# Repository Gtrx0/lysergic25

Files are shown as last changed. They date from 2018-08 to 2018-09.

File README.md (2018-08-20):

# Lysergic 25
5x5 Macropad PCB

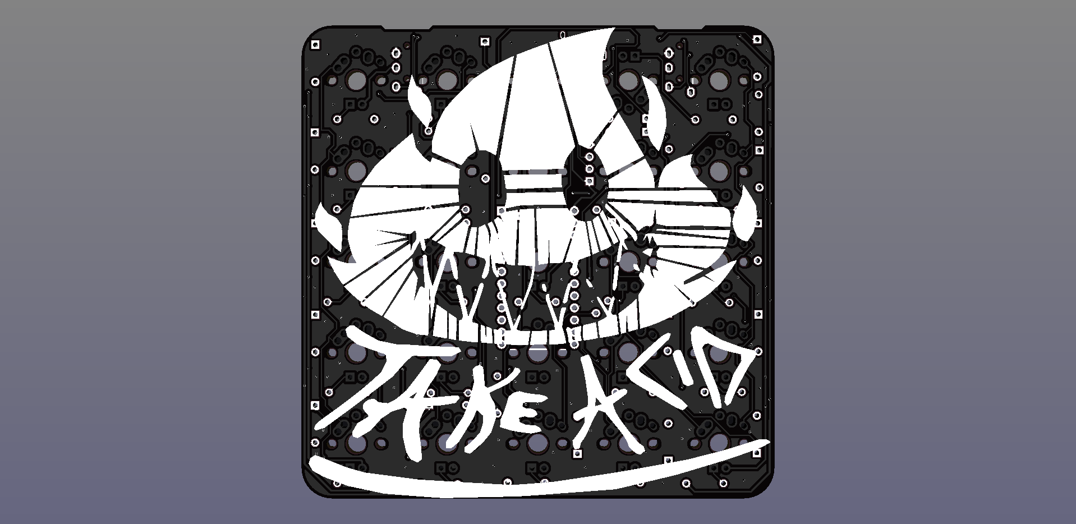
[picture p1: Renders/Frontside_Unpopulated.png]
Frontside Render

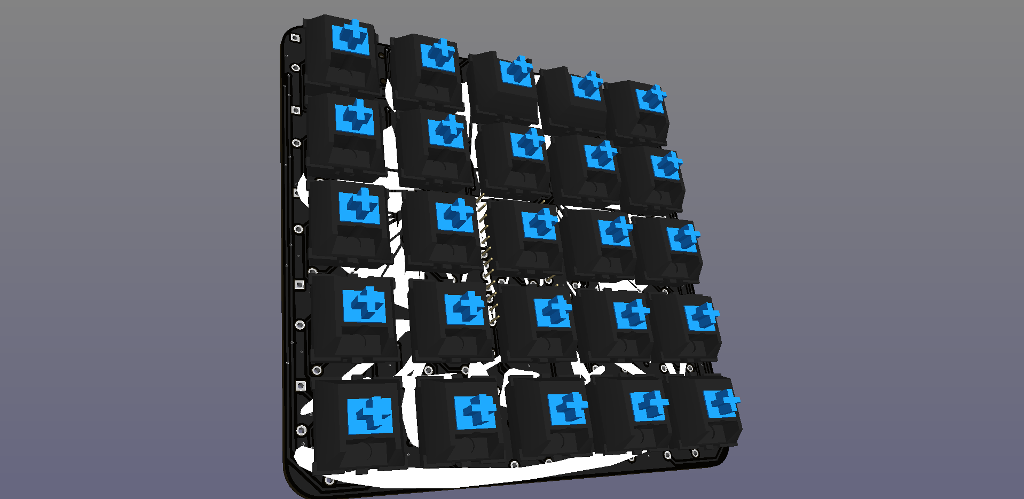
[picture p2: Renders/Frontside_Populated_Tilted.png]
Frontside Render

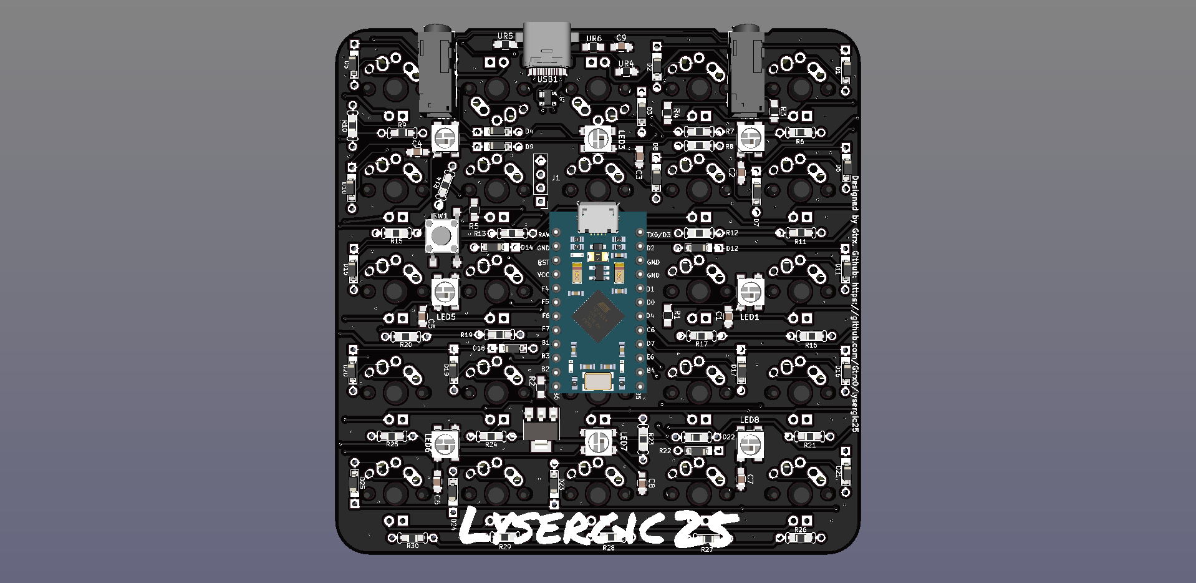
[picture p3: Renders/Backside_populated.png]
Backside Render

# [Layout](http://www.keyboard-layout-editor.com/#/gists/2997f919e892d07fd131f2b731a871e9)

## Features
* In-switch LED support.
* Individually addressible RGB underglow provided by 8 separate WS2812B LEDs.
* USB micro B to USB type-C converter which works like the one ergodox, so no more ripped off usb ports on your pro micro.
* Compatible with Cherry MX ALPS and Kailh CHOC switches. 
* Pro Micro microcontroller for easy diy assembly.
* USB ESD protection circuit.
* 0805 SMD and through hole Diode/resistor compatibility for ease of assembly.

## Warning
KiCad 5 or above is needed to open this project. KiCad 4 or below won't work.

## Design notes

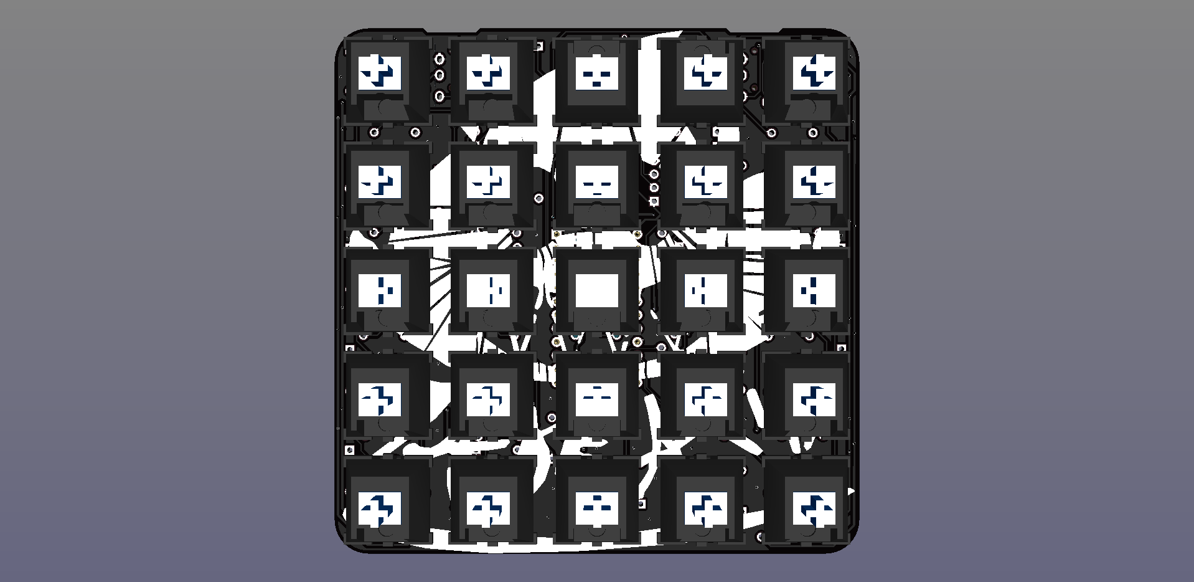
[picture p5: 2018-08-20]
Renders/Frontside_Populated.png

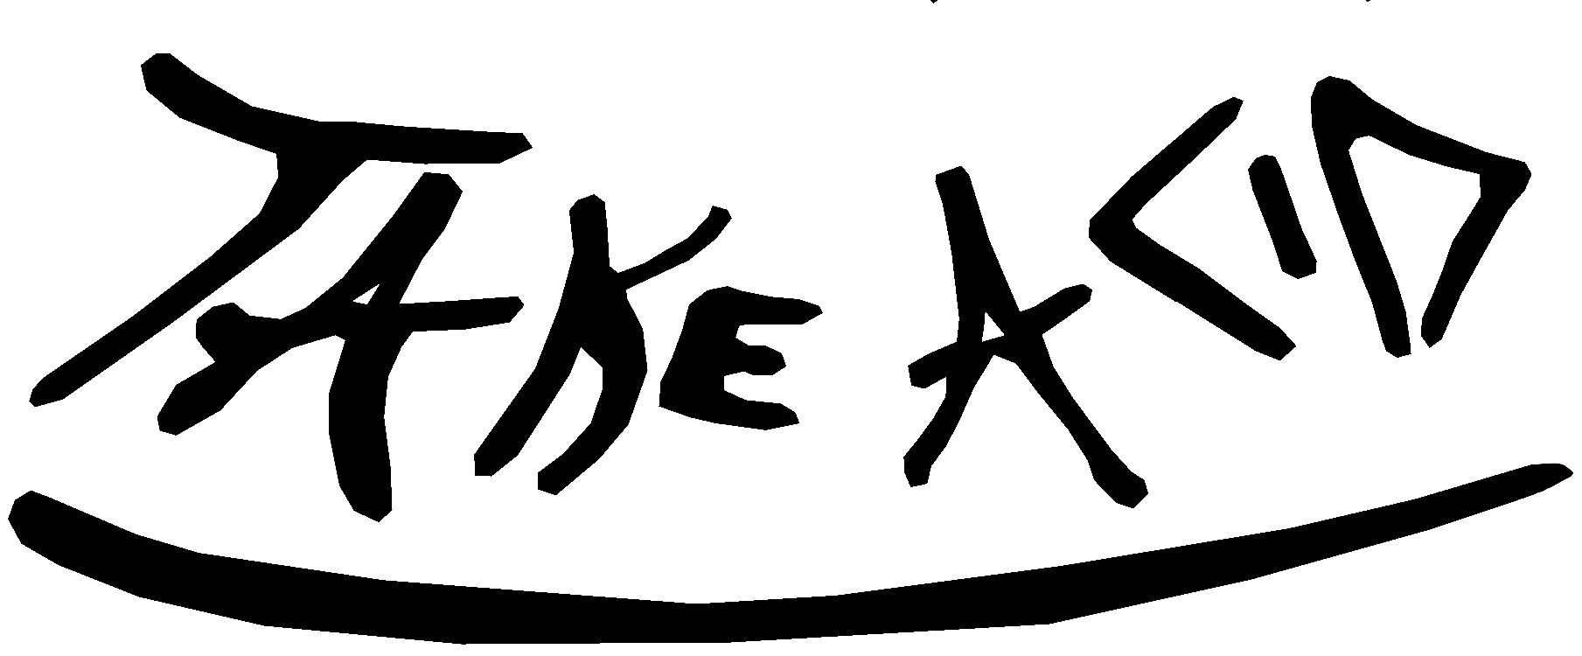
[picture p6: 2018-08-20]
Take_Acid/TAKEACID_text.bmp

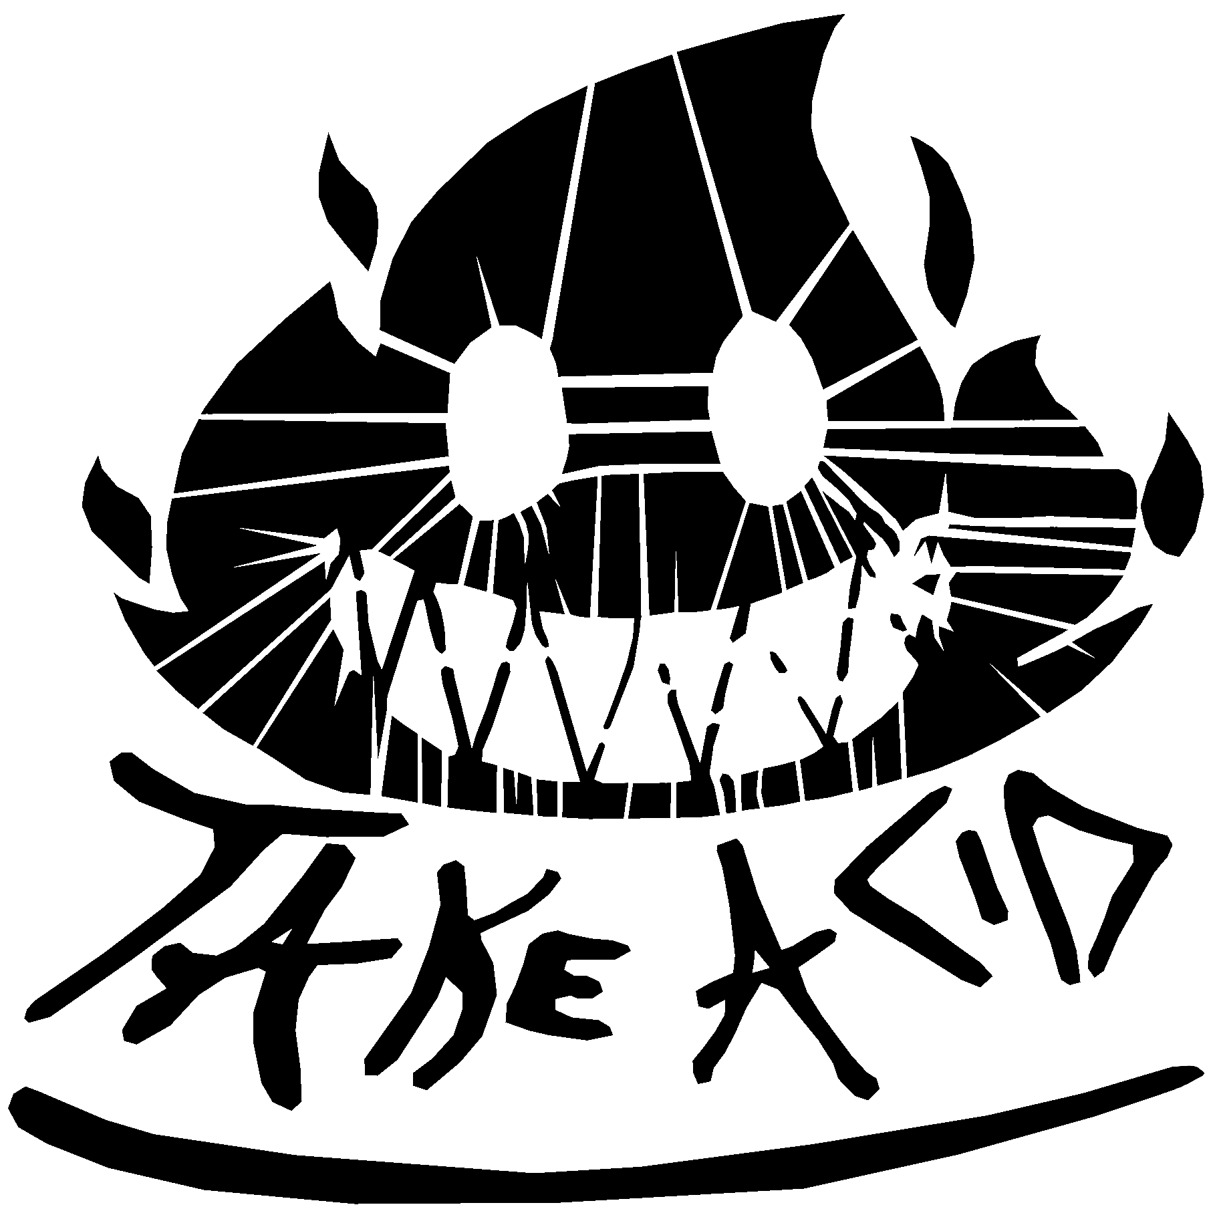
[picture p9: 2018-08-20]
Take_Acid/TAKEACID.bmp

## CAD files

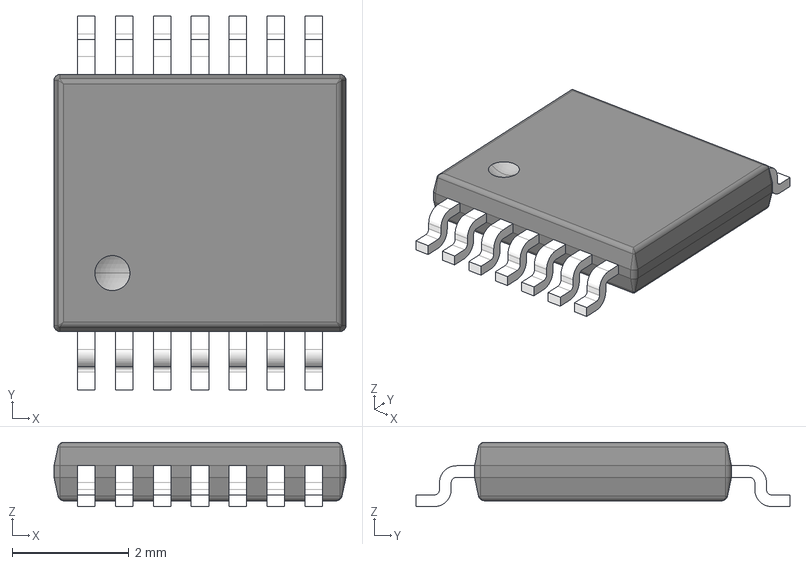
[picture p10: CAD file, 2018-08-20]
Nexperia/Nexperia/3D/SOT402 MO153 TSSOP14-1.step
5.00 x 6.40 x 1.10 mm

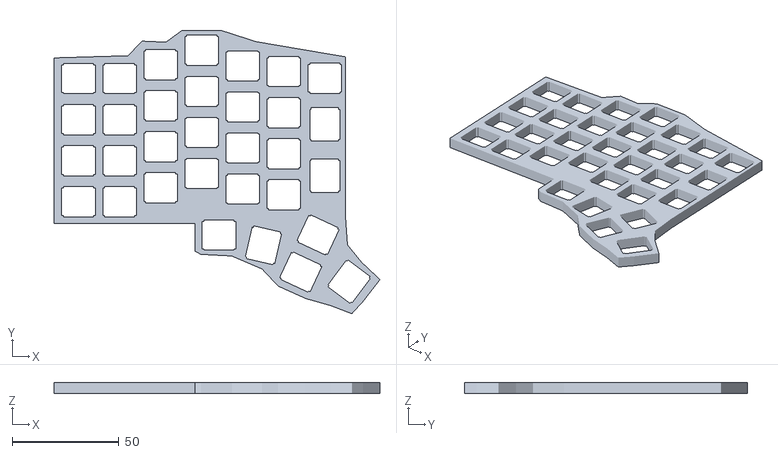
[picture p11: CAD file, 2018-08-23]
Plate/3d print PLATE and CASE (HIGHLY EXPERIMENTAL, 99% WONT WORK)/DNA 2 for thumbs.stl
152.6 x 132.7 x 5.36

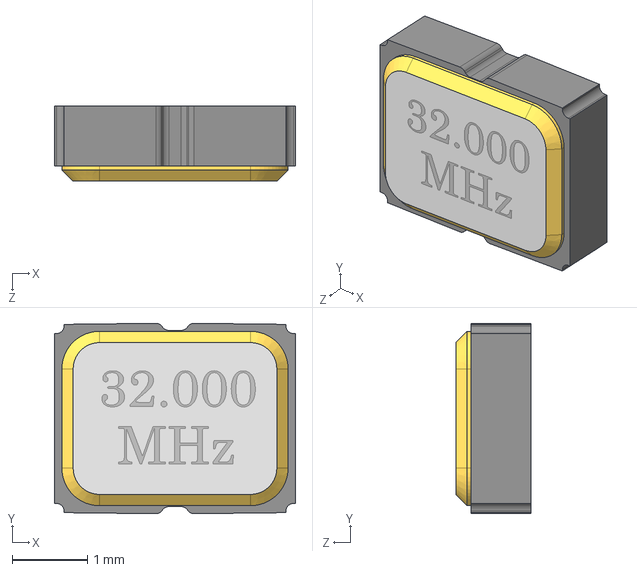
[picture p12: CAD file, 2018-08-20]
3D/OSC3225.STEP
3.20 x 2.53 x 1.00 mm

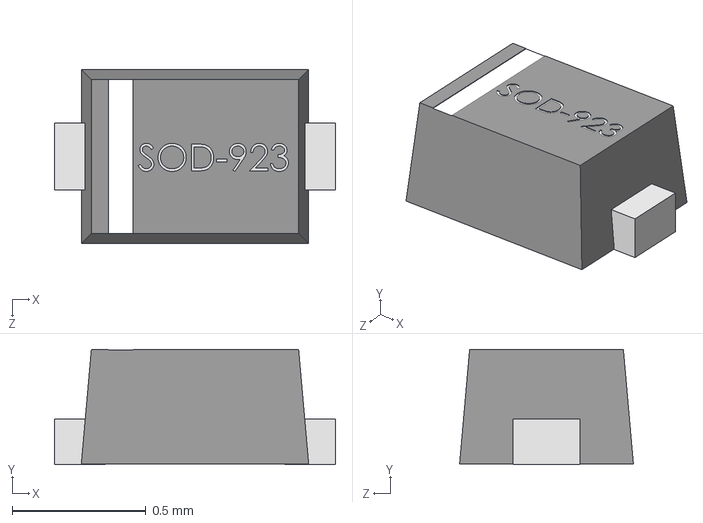
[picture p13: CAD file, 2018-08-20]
Nexperia/Nexperia/3D/SOD923.step
1.05 x 0.43 x 0.65 mm

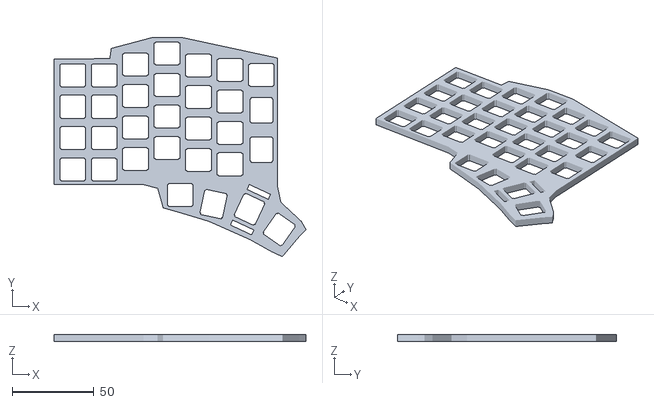
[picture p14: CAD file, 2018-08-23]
Plate/3d print PLATE and CASE (HIGHLY EXPERIMENTAL, 99% WONT WORK)/dna plate non weird.stl
153.9 x 133.9 x 4.29

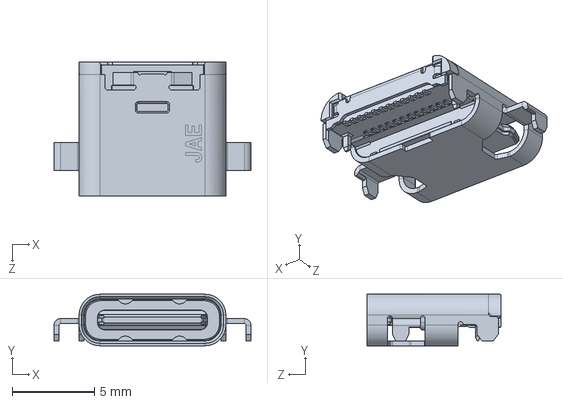
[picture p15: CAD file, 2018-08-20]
3D/K3D-DX07B024JJ1-V1_JAE_Proprietary.STEP
12.0 x 3.14 x 8.17 mm

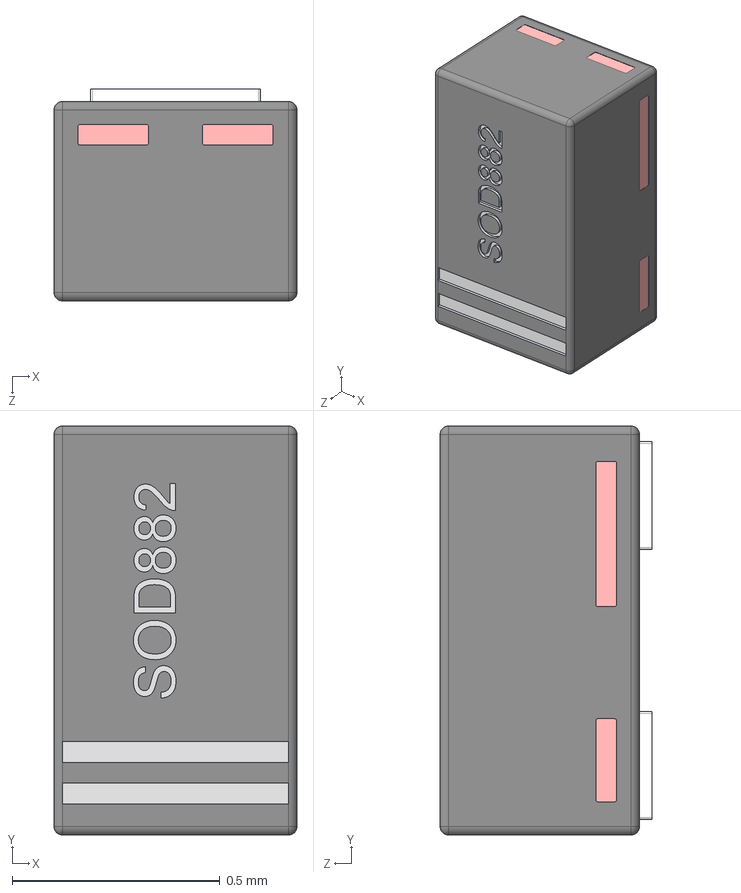
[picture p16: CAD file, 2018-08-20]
Nexperia/Nexperia/3D/SOD882-1.step
0.585 x 0.985 x 0.51 mm

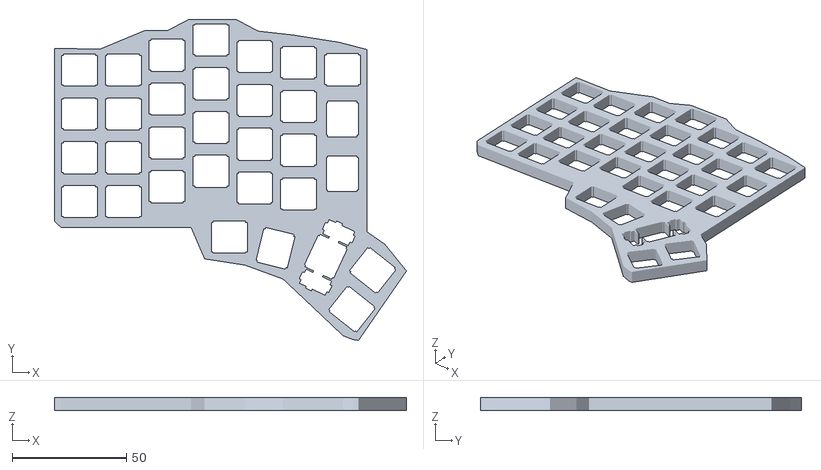
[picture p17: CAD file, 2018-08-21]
Plate/3d print PLATE and CASE (HIGHLY EXPERIMENTAL, 99% WONT WORK)/DNAPLATEREV2.stl
154.2 x 140.6 x 5.71

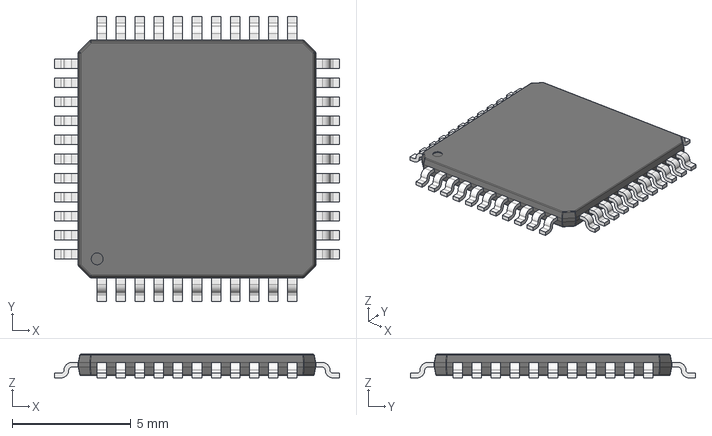
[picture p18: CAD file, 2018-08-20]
3D/qfp80p-10mmx10mm-44 v1.step
12.0 x 12.0 x 1.00 mm
icbody
pin0.25mm x 44

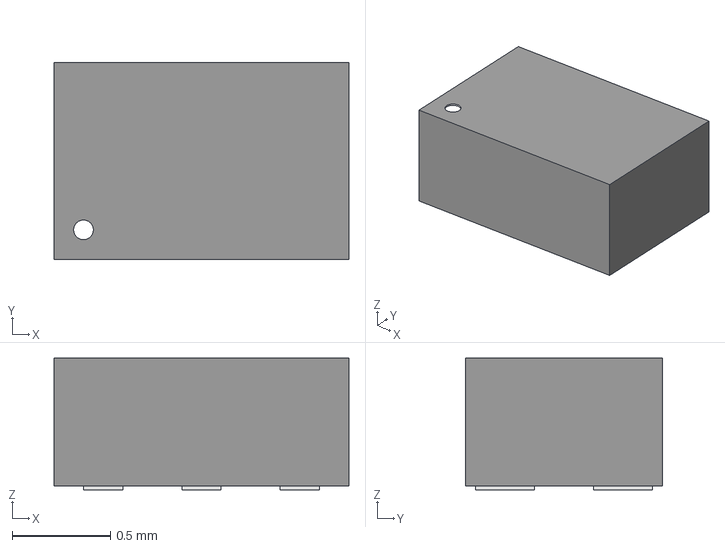
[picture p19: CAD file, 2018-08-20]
Nexperia/Nexperia/3D/MO-252D-UAAD.step
1.50 x 1.00 x 0.67 mm

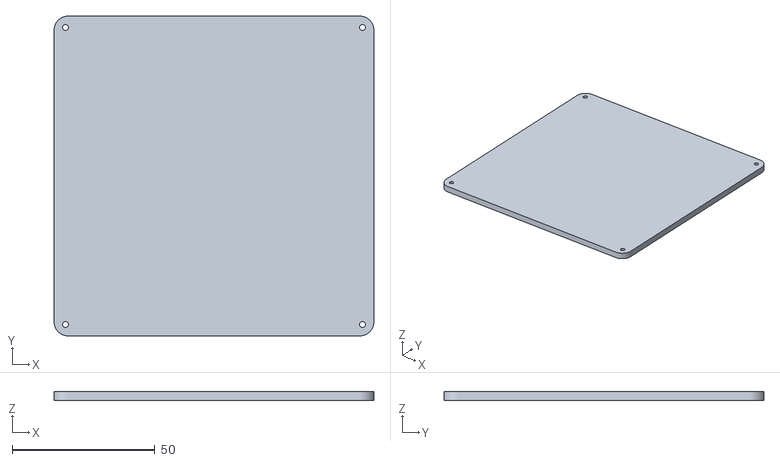
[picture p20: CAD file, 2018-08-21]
Plate/3d print PLATE and CASE (HIGHLY EXPERIMENTAL, 99% WONT WORK)/Lysergic_bottomPLATE.stl
112.1 x 112.1 x 3.01

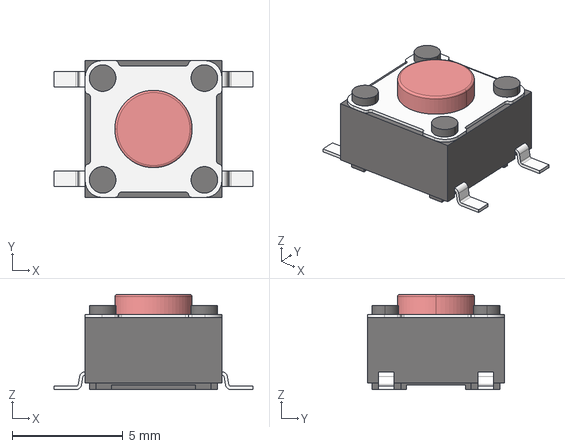
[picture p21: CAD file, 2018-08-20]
3D/Tact Switch SMD 6x6mm.stp
9.00 x 6.20 x 4.30 mm

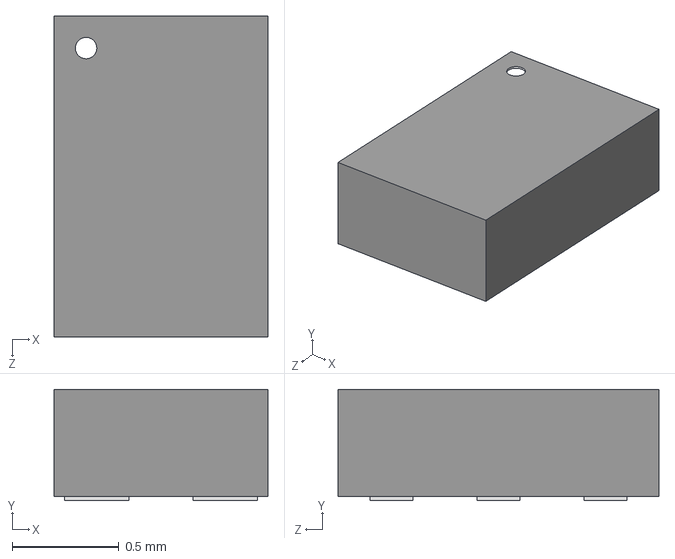
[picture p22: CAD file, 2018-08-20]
Nexperia/Nexperia/3D/MO-252DX1510D-6pin.STEP
1.00 x 0.52 x 1.50 mm

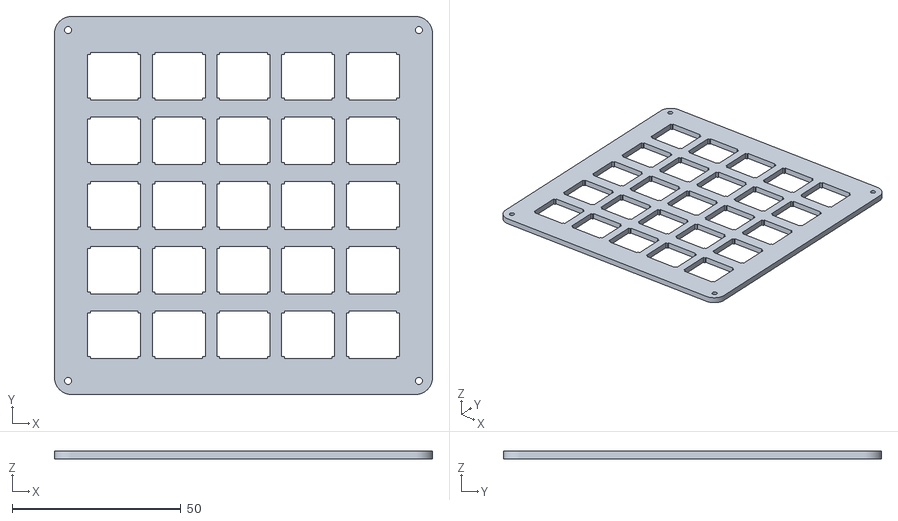
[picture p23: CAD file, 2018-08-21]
Plate/3d print PLATE and CASE (HIGHLY EXPERIMENTAL, 99% WONT WORK)/lysergicPLATE.stl
112.1 x 112.1 x 2.30

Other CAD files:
3D/WS2812_RGB_LED_updated.stp
Nexperia/Nexperia/3D/User Library-MO-252DU1510D (UAAD).STEP
3D/res1206r.STEP
Nexperia/Nexperia/3D/MO-252DU1510D (UAAD)-4pin.STEP
3D/FC68128.STEP
3D/TO-253AA.stp
Nexperia/Nexperia/3D/SC-70-6.stp
Nexperia/Nexperia/3D/SOT402 MO153 TSSOP14-1_orig.step

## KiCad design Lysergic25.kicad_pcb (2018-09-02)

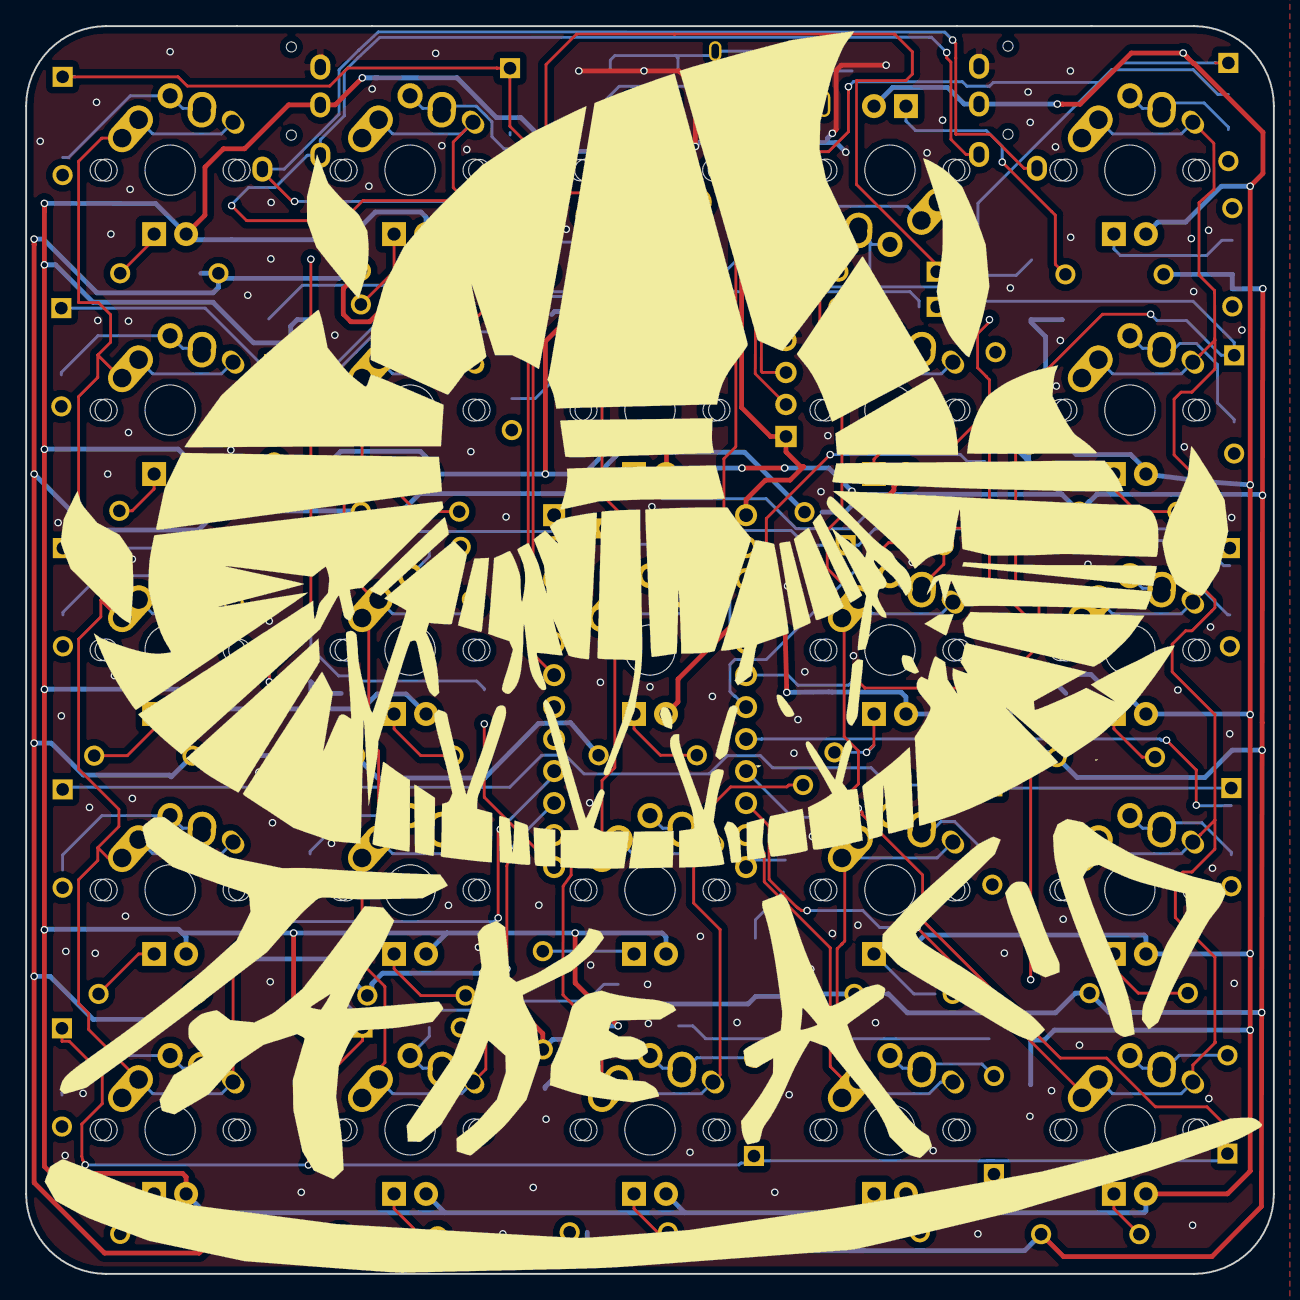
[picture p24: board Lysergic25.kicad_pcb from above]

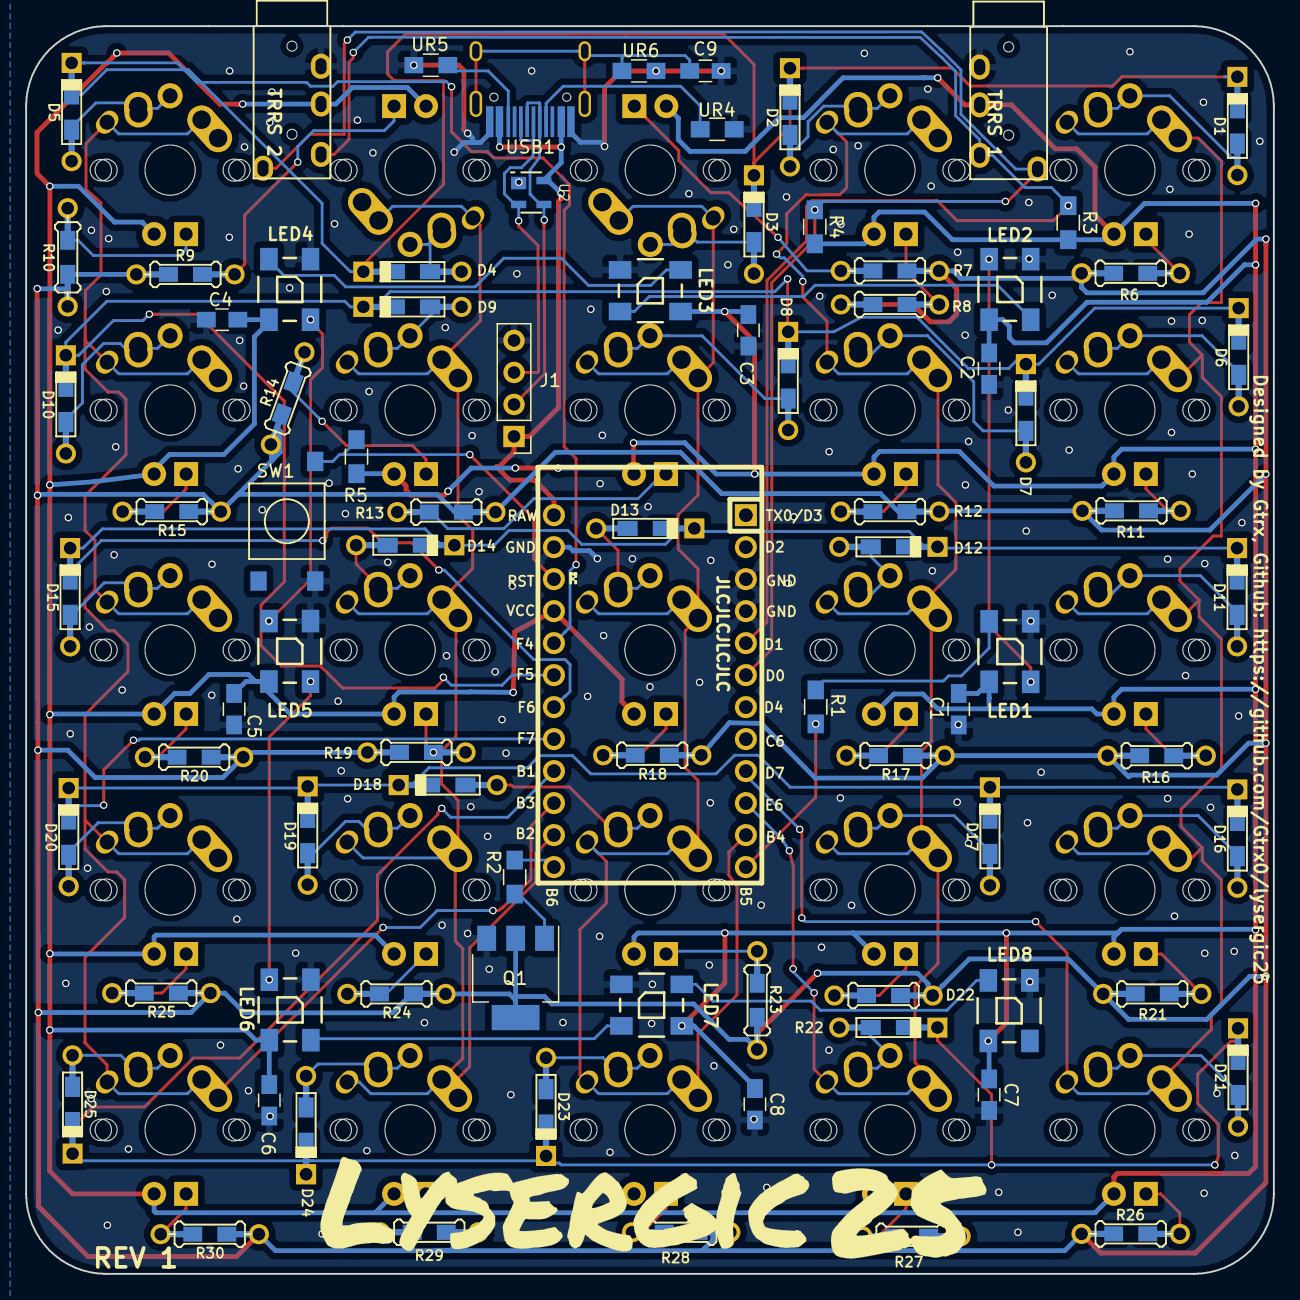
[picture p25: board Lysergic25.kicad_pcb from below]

Board: 2 copper layers, 99.1 x 99.1 mm, 108 parts (31 on the bottom side), 83 nets.

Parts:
C1, C2, C3, C4, C5, C6, C7, C8: 0.1uF; C_0805_HandSoldering
C9: 4.7uF; C_0805_HandSoldering
D1, D2, D3, D4, D5, D6, D7, D8, D9, D10, D11, D12, D13, D14, D15, D16, D17, D18, D19, D20, D21, D22, D23, D24, D25: D; Diode-Hybrid-Back
J1: Breakout; Pin_Header_Straight_1x04_Pitch2.54mm
LED1, LED2, LED3, LED4, LED5, LED6, LED7, LED8: WS2812B
MX1, MX2, MX3, MX4, MX5, MX6, MX7, MX8, MX9, MX10, MX11, MX12, MX14, MX15, MX16, MX17, MX18, MX19, MX20, MX21, MX22, MX23, MX24, MX25: MX-1U; MX-1U-FLIPPED
MX13: MX-1U; MX-1U-FLIPPED_No_Hole
Q1: Q_NPN_BCE; SOT-223-3_TabPin2
R1: 470; R_0805_HandSoldering
R2: 1.5k; R_0805_HandSoldering
R3, R4: 2.2K; R_0805_HandSoldering
R5: 100k; R_0805_HandSoldering
R6, R7, R8, R9, R10, R11, R12, R13, R14, R15, R16, R17, R18, R19, R20, R21, R22, R23, R24, R25, R26, R27, R28, R29, R30: R; Resistor-Hybrid-Back
SW1: SW_PUSH; CandK_6x6mm_Tactile
Trrs1, Trrs2: Audio-Jack-4; TRRS-PJ-320A
U1: Pro_Micro; ArduinoProMicro
U2: PRTR5V0U2X; SOT143B
UR4, UR5: 5.1K; R_0805_HandSoldering
UR6: 1M; R_0805_HandSoldering
USB1: HRO-TYPE-C-31-M-12; HRO-TYPE-C-31-M-12-HandSoldering

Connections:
+5V: J1.1, U1.24, U2.4, USB1.2, USB1.11
COL0: MX1.1, MX6.1, MX11.1, MX16.1, MX21.1, U1.9
COL1: MX2.1, MX7.1, MX12.1, MX17.1, MX22.1, U1.10
COL2: MX3.1, MX8.1, MX13.1, MX18.1, MX23.1, U1.11
COL3: MX4.1, MX9.1, MX14.1, MX19.1, MX24.1, U1.14
COL4: MX5.1, MX10.1, MX15.1, MX20.1, MX25.1, U1.15
D+: J1.3, U2.2, USB1.6, USB1.8
D-: J1.2, U2.3, USB1.5, USB1.7
GND: C1.2, C2.2, C3.2, C4.2, C5.2, C6.2, C7.2, C8.2, C9.2, J1.4, LED1.3, LED2.3, LED3.3, LED4.3, LED5.3, LED6.3, LED7.3, LED8.3, Q1.3, SW1.2, Trrs1.4, Trrs2.4, U1.3, U1.4, U1.23, U2.1, UR4.1, UR5.2, UR6.1, USB1.1, USB1.12
LEDGND: Q1.2, R6.2, R7.2, R8.2, R9.2, R10.2, R11.2, R12.2, R13.2, R14.2, R15.2, R16.2, R17.2, R18.2, R19.2, R20.2, R21.2, R22.2, R23.2, R24.2, R25.2, R26.2, R27.2, R28.2, R29.2, R30.2
unnamed: C9.1, UR6.2, USB1.13
unnamed: D1.2, MX1.2
unnamed: D2.2, MX2.2
unnamed: D3.2, MX3.2
unnamed: D4.2, MX4.2
unnamed: D5.2, MX5.2
unnamed: D6.2, MX6.2
unnamed: D7.2, MX7.2
unnamed: D8.2, MX8.2
unnamed: D9.2, MX9.2
unnamed: D10.2, MX10.2
unnamed: D11.2, MX11.2
unnamed: D12.2, MX12.2
unnamed: D13.2, MX13.2
unnamed: D14.2, MX14.2
unnamed: D15.2, MX15.2
unnamed: D16.2, MX16.2
unnamed: D17.2, MX17.2
unnamed: D18.2, MX18.2
unnamed: D19.2, MX19.2
unnamed: D20.2, MX20.2
unnamed: D21.2, MX21.2
unnamed: D22.2, MX22.2
unnamed: D23.2, MX23.2
unnamed: D24.2, MX24.2
unnamed: D25.2, MX25.2
unnamed: LED1.2, LED2.4
unnamed: LED1.4, R1.2
unnamed: LED2.2, LED3.4
unnamed: LED3.2, LED4.4
unnamed: LED4.2, LED5.4
unnamed: LED5.2, LED6.4
unnamed: LED6.2, LED7.4
unnamed: LED7.2, LED8.4
unnamed: MX1.4, R6.1
unnamed: MX2.4, R7.1
unnamed: MX3.4, R8.1
unnamed: MX4.4, R9.1
unnamed: MX5.4, R10.1
unnamed: MX6.4, R11.1
unnamed: MX7.4, R12.1
unnamed: MX8.4, R13.1
unnamed: MX9.4, R14.1
unnamed: MX10.4, R15.1
unnamed: MX11.4, R16.1
unnamed: MX12.4, R17.1
unnamed: MX13.4, R18.1
unnamed: MX14.4, R19.1
unnamed: MX15.4, R20.1
unnamed: MX16.4, R21.1
unnamed: MX17.4, R22.1
unnamed: MX18.4, R23.1
unnamed: MX19.4, R24.1
unnamed: MX20.4, R25.1
unnamed: MX21.4, R26.1
unnamed: MX22.4, R27.1
unnamed: MX23.4, R28.1
unnamed: MX24.4, R29.1
unnamed: MX25.4, R30.1
unnamed: Q1.1, R2.1
unnamed: R5.2, SW1.1, U1.22
unnamed: UR4.2, USB1.4
unnamed: UR5.1, USB1.10
PWMIN: R2.2, U1.13
RGBIN: R1.1, U1.12
ROW0: D1.1, D2.1, D3.1, D4.1, D5.1, U1.20
ROW1: D6.1, D7.1, D8.1, D9.1, D10.1, U1.19
ROW2: D11.1, D12.1, D13.1, D14.1, D15.1, U1.18
ROW3: D16.1, D17.1, D18.1, D19.1, D20.1, U1.17
ROW4: D21.1, D22.1, D23.1, D24.1, D25.1, U1.16
SCL: R4.1, Trrs1.1, Trrs2.1, U1.6
SDA: R3.1, Trrs1.2, Trrs2.2, U1.5
VCC: C1.1, C2.1, C3.1, C4.1, C5.1, C6.1, C7.1, C8.1, LED1.1, LED2.1, LED3.1, LED4.1, LED5.1, LED6.1, LED7.1, LED8.1, MX1.3, MX2.3, MX3.3, MX4.3, MX5.3, MX6.3, MX7.3, MX8.3, MX9.3, MX10.3, MX11.3, MX12.3, MX13.3, MX14.3, MX15.3, MX16.3, MX17.3, MX18.3, MX19.3, MX20.3, MX21.3, MX22.3, MX23.3, MX24.3, MX25.3, R3.2, R4.2, R5.1, Trrs1.3, Trrs2.3, U1.21

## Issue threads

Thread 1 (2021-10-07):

One of the jacks is flipped

avr6ude, 2021-10-07:
Recieved PCB from manufacturers, put the jacks in and one of their footprints is flipped. Checked sources, flipped in there too. Same fo 3D view in KiCAD.
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
